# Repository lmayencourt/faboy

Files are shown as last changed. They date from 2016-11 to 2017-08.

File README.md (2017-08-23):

# faboy
arduboy clone for the fablab of Sion (CH)

## faboyBLE (V2)
The new version of the faboy is based on a nrf52822 module, an ARM cortex M0+ based processor with Bluetooth Smart. This will allow the possibility to change game wia BLE or UART and to have multiplayer games.  
### status
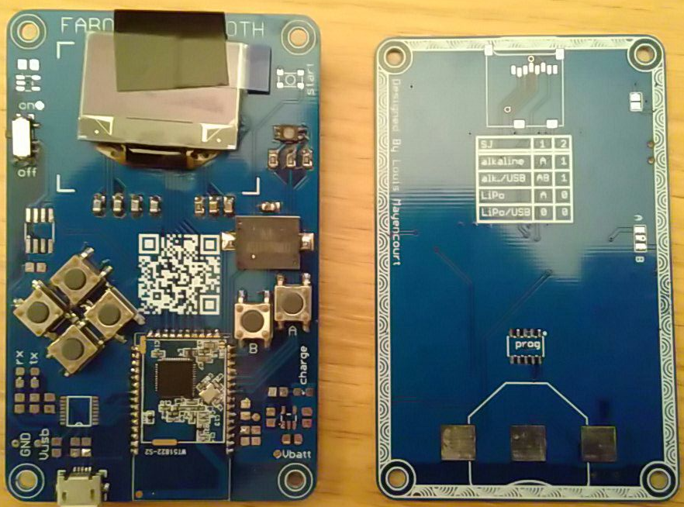
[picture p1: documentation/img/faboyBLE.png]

* PCB designed, ordered and mounted

### issues 
* cannot programm the nrf module...

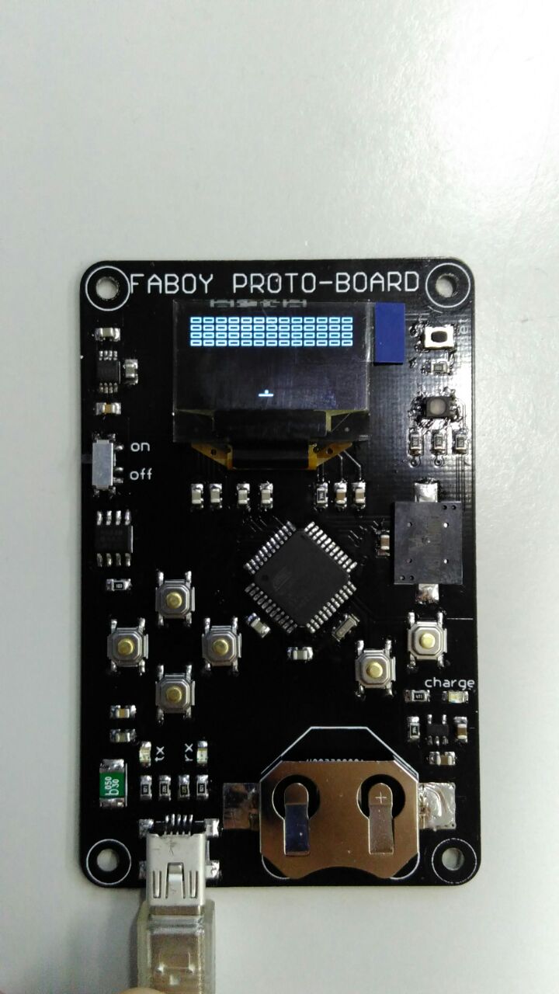
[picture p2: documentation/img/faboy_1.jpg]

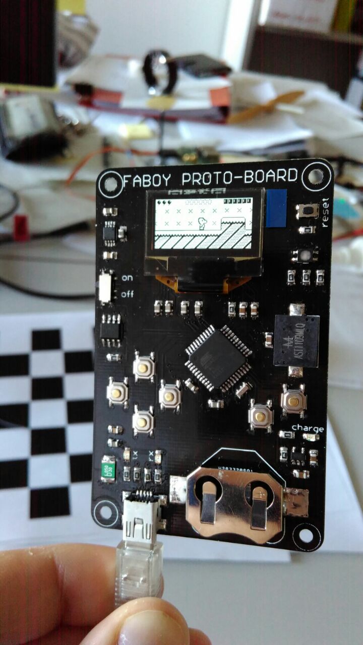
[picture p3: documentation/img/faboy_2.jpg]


## idea for v2 
  * NRF24l for a wireless communication
  * capacitive button
  * coin-cell battery / thin film battery 
  * different switch pattern
  * ARM processor 
  * solar cell
  * PCB usb connector 
  * battery monitoring with ADC

## issues 
  * bad usb connector (mini b instead of micro b !)
  * difficult to find a gnd test pad on the top 
  * battery operation crash after a small moment

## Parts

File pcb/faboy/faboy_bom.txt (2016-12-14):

Partlist exported from /home/louis/eagle/faboy/pcb/faboy/faboy.sch at 01.12.16 16:03

Part Value                           Device                          Package                       Description                                                                             PROD_ID    VALUE
BAT1                                 BATTERY20SMD                    BATTCON_20MM                  Battery Holders                                                                                         
C1   1uF                             C-EUC0805K                      C0805K                        CAPACITOR, European symbol                                                                              
C2   1uF                             C-EUC0805K                      C0805K                        CAPACITOR, European symbol                                                                              
C3   4.7uF / 10v                     C-EUC0805K                      C0805K                        CAPACITOR, European symbol                                                                              
C4   2.2uF                           C-EUC0805K                      C0805K                        CAPACITOR, European symbol                                                                              
C5   1uF                             C-EUC0805K                      C0805K                        CAPACITOR, European symbol                                                                              
C6   1uF                             C-EUC0805K                      C0805K                        CAPACITOR, European symbol                                                                              
C7   1uF                             C-EUC0805K                      C0805K                        CAPACITOR, European symbol                                                                              
C8   1uF                             C-EUC0805K                      C0805K                        CAPACITOR, European symbol                                                                              
C9   0.1uF                           C-EUC0805K                      C0805K                        CAPACITOR, European symbol                                                                              
C10  1uF                             C-EUC0805K                      C0805K                        CAPACITOR, European symbol                                                                              
C11  0.47uF                          C-EUC0805K                      C0805K                        CAPACITOR, European symbol                                                                              
C12  2.2uF                           C-EUC0805K                      C0805K                        CAPACITOR, European symbol                                                                              
C13  2.2uF                           C-EUC0805K                      C0805K                        CAPACITOR, European symbol                                                                              
C14  4.7uF                           C-EUC0805K                      C0805K                        CAPACITOR, European symbol                                                                              
C15  4.7uF                           C-EUC0805K                      C0805K                        CAPACITOR, European symbol                                                                              
C16  4.7uF                           C-EUC0805K                      C0805K                        CAPACITOR, European symbol                                                                              
F1   500mA                           PTCFUSE-1812                    1812                          PTC fuses, resettable thermistors                                                                       
J1   USB-MICROBREDUCED_PASTE         USB-MICROBREDUCED_PASTE         USB-B-MICRO-SMD_V03_RED_PASTE RED_PASTE version has 70% paste area under D+ D- USBID pins for applications            CONN-11752      
J2                                   M06SMD-FEMALE-V2                1X06-SMD-FEMALE-V2            Header 6                                                                                CONN-09668      
LED1                                 LEDSML0805                      SML0805                       LED                                                                                                     
LED2                                 LEDSML0805                      SML0805                       LED                                                                                                     
LED3                                 LEDSML0805                      SML0805                       LED                                                                                                     
R1   390k                            R-EU_R0805                      R0805                         RESISTOR, European symbol                                                                               
R2   10k                             R-EU_R0805                      R0805                         RESISTOR, European symbol                                                                               
R3   22                              R-EU_R0805                      R0805                         RESISTOR, European symbol                                                                               
R4   22                              R-EU_R0805                      R0805                         RESISTOR, European symbol                                                                               
R5   820                             R-EU_R0805                      R0805                         RESISTOR, European symbol                                                                               
R6   820                             R-EU_R0805                      R0805                         RESISTOR, European symbol                                                                               
R7   390k                            R-EU_R0805                      R0805                         RESISTOR, European symbol                                                                               
R8   470                             R-EU_R0805                      R0805                         RESISTOR, European symbol                                                                               
R9   820                             R-EU_R0805                      R0805                         RESISTOR, European symbol                                                                               
R10  820                             R-EU_R0805                      R0805                         RESISTOR, European symbol                                                                               
R11  820                             R-EU_R0805                      R0805                         RESISTOR, European symbol                                                                               
R12  10k                             R-EU_R0805                      R0805                         RESISTOR, European symbol                                                                               
S1   SWITCH-MOMENTARY-2SMD-REDUNDANT SWITCH-MOMENTARY-2SMD-REDUNDANT TACTILE-SWITCH-SMD            Various NO switches- pushbuttons, reed, etc                                             SWCH-08247      
S2   SWITCH-MOMENTARY-2SMD-REDUNDANT SWITCH-MOMENTARY-2SMD-REDUNDANT TACTILE-SWITCH-SMD            Various NO switches- pushbuttons, reed, etc                                             SWCH-08247      
S3   SWITCH-MOMENTARY-2SMD-REDUNDANT SWITCH-MOMENTARY-2SMD-REDUNDANT TACTILE-SWITCH-SMD            Various NO switches- pushbuttons, reed, etc                                             SWCH-08247      
S4   SWITCH-MOMENTARY-2SMD-REDUNDANT SWITCH-MOMENTARY-2SMD-REDUNDANT TACTILE-SWITCH-SMD            Various NO switches- pushbuttons, reed, etc                                             SWCH-08247      
S5                                   SWITCH-SPDT-SMD-A               SWITCH-SPST-SMD-A             SPDT Switch                                                                             SWCH-10651      
S6   SWITCH-MOMENTARY-2SMD-REDUNDANT SWITCH-MOMENTARY-2SMD-REDUNDANT TACTILE-SWITCH-SMD            Various NO switches- pushbuttons, reed, etc                                             SWCH-08247      
S7   SWITCH-MOMENTARY-2SMD-REDUNDANT SWITCH-MOMENTARY-2SMD-REDUNDANT TACTILE-SWITCH-SMD            Various NO switches- pushbuttons, reed, etc                                             SWCH-08247      
S8   SWITCH-MOMENTARY-2SMD-3         SWITCH-MOMENTARY-2SMD-3         TACTILE_SWITCH_SMD-3          Various NO switches- pushbuttons, reed, etc                                                             
SG1  BUZZERSMD3                      BUZZERSMD3                      BUZZER-CMT1102                Buzzer 12mm                                                                                             
SJ1  direct power                    SJ                              SJ                            SMD solder JUMPER                                                                                       
SJ3  direct path                     SJ2W                            SJ_2                          SMD solder JUMPER                                                                                       
U$1  UG-2864HSWEG01                  UG-2864HSWEG01                  1X30-0.7MM                    UG-2864HSWEG01 OLED display                                                                             
U$2  ATMEGA32U4-AU                   ATMEGA32U4-AU                   TQFP44                        http://www.ladyada.net/library/eagle                                                                    
U$7  LED-RGB-P-LCC-4                 LED-RGB-P-LCC-4                 P-LCC-4-3                                                                                                                             
U$8  SI4833BDY                       SI4833BDY                       SO08                                                                                                                                  
U1   MAX1595UMAX                     MAX1595UMAX                     UMAX8                         max1595 buck/boost dcdc 3.3v output                                                                     
U2   MCP73831                        MCP73831                        SOT23-5                       Miniature single cell, fully integrated Li-Ion, Li-polymer charge management controller IC-09995        
Y1   16MHZ                           RESONATOR16MHZ                  RESONATOR-SMD                 Resonator                                                                               XTAL-08900 16MHZ

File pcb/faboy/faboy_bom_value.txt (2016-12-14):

Partlist exported from /home/louis/eagle/faboy/pcb/faboy/faboy.sch at 01.12.16 16:02

Qty Value                           Device                          Package                       Parts                       Description                                                                             PROD_ID    VALUE
1                                   BATTERY20SMD                    BATTCON_20MM                  BAT1                        Battery Holders                                                                                         
3                                   LEDSML0805                      SML0805                       LED1, LED2, LED3            LED                                                                                                     
1                                   M06SMD-FEMALE-V2                1X06-SMD-FEMALE-V2            J2                          Header 6                                                                                CONN-09668      
1                                   SWITCH-SPDT-SMD-A               SWITCH-SPST-SMD-A             S5                          SPDT Switch                                                                             SWCH-10651      
1   0.1uF                           C-EUC0805K                      C0805K                        C9                          CAPACITOR, European symbol                                                                              
1   0.47uF                          C-EUC0805K                      C0805K                        C11                         CAPACITOR, European symbol                                                                              
2   10k                             R-EU_R0805                      R0805                         R2, R12                     RESISTOR, European symbol                                                                               
1   16MHZ                           RESONATOR16MHZ                  RESONATOR-SMD                 Y1                          Resonator                                                                               XTAL-08900 16MHZ
7   1uF                             C-EUC0805K                      C0805K                        C1, C2, C5, C6, C7, C8, C10 CAPACITOR, European symbol                                                                              
3   2.2uF                           C-EUC0805K                      C0805K                        C4, C12, C13                CAPACITOR, European symbol                                                                              
2   22                              R-EU_R0805                      R0805                         R3, R4                      RESISTOR, European symbol                                                                               
2   390k                            R-EU_R0805                      R0805                         R1, R7                      RESISTOR, European symbol                                                                               
3   4.7uF                           C-EUC0805K                      C0805K                        C14, C15, C16               CAPACITOR, European symbol                                                                              
1   4.7uF / 10v                     C-EUC0805K                      C0805K                        C3                          CAPACITOR, European symbol                                                                              
1   470                             R-EU_R0805                      R0805                         R8                          RESISTOR, European symbol                                                                               
1   500mA                           PTCFUSE-1812                    1812                          F1                          PTC fuses, resettable thermistors                                                                       
5   820                             R-EU_R0805                      R0805                         R5, R6, R9, R10, R11        RESISTOR, European symbol                                                                               
1   ATMEGA32U4-AU                   ATMEGA32U4-AU                   TQFP44                        U$2                         http://www.ladyada.net/library/eagle                                                                    
1   BUZZERSMD3                      BUZZERSMD3                      BUZZER-CMT1102                SG1                         Buzzer 12mm                                                                                             
1   LED-RGB-P-LCC-4                 LED-RGB-P-LCC-4                 P-LCC-4-3                     U$7                                                                                                                                 
1   MAX1595UMAX                     MAX1595UMAX                     UMAX8                         U1                          max1595 buck/boost dcdc 3.3v output                                                                     
1   MCP73831                        MCP73831                        SOT23-5                       U2                          Miniature single cell, fully integrated Li-Ion, Li-polymer charge management controller IC-09995        
1   SI4833BDY                       SI4833BDY                       SO08                          U$8                                                                                                                                 
1   SWITCH-MOMENTARY-2SMD-3         SWITCH-MOMENTARY-2SMD-3         TACTILE_SWITCH_SMD-3          S8                          Various NO switches- pushbuttons, reed, etc                                                             
6   SWITCH-MOMENTARY-2SMD-REDUNDANT SWITCH-MOMENTARY-2SMD-REDUNDANT TACTILE-SWITCH-SMD            S1, S2, S3, S4, S6, S7      Various NO switches- pushbuttons, reed, etc                                             SWCH-08247      
1   UG-2864HSWEG01                  UG-2864HSWEG01                  1X30-0.7MM                    U$1                         UG-2864HSWEG01 OLED display                                                                             
1   USB-MICROBREDUCED_PASTE         USB-MICROBREDUCED_PASTE         USB-B-MICRO-SMD_V03_RED_PASTE J1                          RED_PASTE version has 70% paste area under D+ D- USBID pins for applications            CONN-11752      
1   direct path                     SJ2W                            SJ_2                          SJ3                         SMD solder JUMPER                                                                                       
1   direct power                    SJ                              SJ                            SJ1                         SMD solder JUMPER

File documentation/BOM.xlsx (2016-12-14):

 | link | reference | description | price | nbr | total
mouser | http://www.mouser.ch/ProductDetail/Atmel/ATMEGA32U4-AU/?qs=sGAEpiMZZMvAvBNgSS9Lqh1wBIpnYT9c | ATMEGA32u4-AU | 8bits 32k cpu | 6.33 | 1 | 6.33
mouser | http://www.mouser.ch/Search/ProductDetail.aspx?qs=8%2f1pEl6ptNseo9Gxrhu%2fPA%3d%3d | CSTCE16M0V53ZW-R0 | resonator 16Mhz | 0.5 | 1 | 0.5
mouser | http://www.mouser.ch/ProductDetail/Microchip-Technology/MCP73831T-2ACI-OT/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 | MCP73831 | MCP73831 LiPo charger | 0.6 | 1 | 0.6
mouser | http://www.mouser.ch/ProductDetail/Maxim-Integrated/MAX1595EUA33+/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 | MAX1595EUA33 | buck/boost 3.3v dcdc | 3.88 | 1 | 3.88
mouser | http://www.mouser.ch/ProductDetail/Vishay/SI4833BDY-T1-GE3/ | SI4833BDY | P-mosfet with schottky | 0.66 | 1 | 0.66
mouser |  | UJ2-MBH-1-SMT | conn USB mini B femal | 0.78 | 1 | 0.78
mouser |  |  | conn USB Micro B femal | 0.7 | 1 | 0.7
mouser |  | AP2012SRCPRV | led red | 0.14 |  | 0
mouser |  | LTST-C170TBKT | led blue | 0.4 |  | 0
mouser |  | APT2012SGC | led green | 0.14 |  | 0
mouser | http://www.mouser.ch/ProductDetail/Mallory-Sonalert/AST1109MLTRQ/ | AST1109MLTRQ | piezzo | 3.2 | 1 | 3.2
mouser | http://www.mouser.ch/ProductDetail/ALPS/SKQGAKE010/?qs=sGAEpiMZZMtFyPk3yBMYYCtu4vPfeeUaHHDNk5wDwBc%3d | SKQGAKE010 | push button | 0.16 | 6 | 0.96
mouser | http://www.mouser.ch/ProductDetail/CK-Components/SK-12C0405-SG-15-RT/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 | SK-12C0405-SG 1.5 RT | switch on-off | 0.97 | 1 | 0.97
mouser | http://www.mouser.ch/ProductDetail/CK-Components/KMR631NG-ULC-LFS/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 | KMR631NG ULC LFS | reset push buton | 0.27 | 1 | 0.27
mouser | http://www.mouser.ch/ProductDetail/Cree-Inc/CLVBA-FKA-CAEDH8BBB7A363/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 | CLVBA-FKA-CAEDH8BBB7A363 | led RGB | 0.48 | 1 | 0.48
mouser | http://www.mouser.ch/ProductDetail/Linx-Technologies/BAT-HLD-002-SMT/ | BAT-HLD-002-SMT | support CR2016 | 0.28 | 1 | 0.28
alibaba | https://www.alibaba.com/product-detail/2016-hot-sale-lithium-polymer-battery_60437032979.html | GEB014461 | LiPo 3.6V 180 mAh | 5 | 0 | 0
buydisplay | http://www.buydisplay.com/default/datasheet-128x64-oled-module-spi-0-96-inch-graphic-displays-white-on-black | ER-OLED0.96-1 | oled white on black 128x64 0.96'' | 3.61 | 0 | 0
buydisplay | http://www.buydisplay.com/default/serial-spi-1-3-inch-128x64-oled-display-module-ssd1306-white-on-black | ER-OLED013-1W | oled white on black 128x64 1.3'' | 6.17 | 1 | 6.17
seeed |  | PCB | pcb 85.6x53.98 x 0.6mm 2 layers black | 3 | 1 | 3
 |  |  |  |  |  | 28.78

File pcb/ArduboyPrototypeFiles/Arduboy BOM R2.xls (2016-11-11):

Arduboy Bill of Materials |  | 2014-03-16
kevin@bateske.com |  | Confidential
Name | Part Number | Link | Qty
OLED DISPLAY | White 0.96 inch 128x64 OLED |  | 1
ATMEGA328P | ATMEGA328P-AU TQFP32 | http://www.mouser.com/ProductDetail/Atmel/ATMEGA328P-AU/ | 1
Resistor 10K Ohm | 0805 10K Ohm Resistor | any 5% is fine | 1
Capacitor 1uF | 0805 1uF Capacitor | any 5% is fine | 2
Rechargable Battery | LIR-2016 | ??? | 1
Speaker | SMT-1141 | http://www.mouser.com/ProductDetail/PUI-Audio/SMT-1141-T-3-R/ | 1
Capacitor .1uF | 0805 .1uF Capacitor | any 5% is fine | 2
Capacitor 10uF | 0805 10uF Capacitor | any 5% is fine | 2
LiPo-Charger | MCP73831 | http://www.mouser.com/ProductDetail/Microchip-Technology/MCP73831T-2ACI-OT/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 | 1
2.2uf
4.7uf
2k
Board Dimensions:
Height: | 85.6mm
Width: | 53.98mm
Thickness: | 1.6mm
Cutouts (Routing) | Qty(5)
Drills: | Qty(8)
Plated Vias | Qty(29)

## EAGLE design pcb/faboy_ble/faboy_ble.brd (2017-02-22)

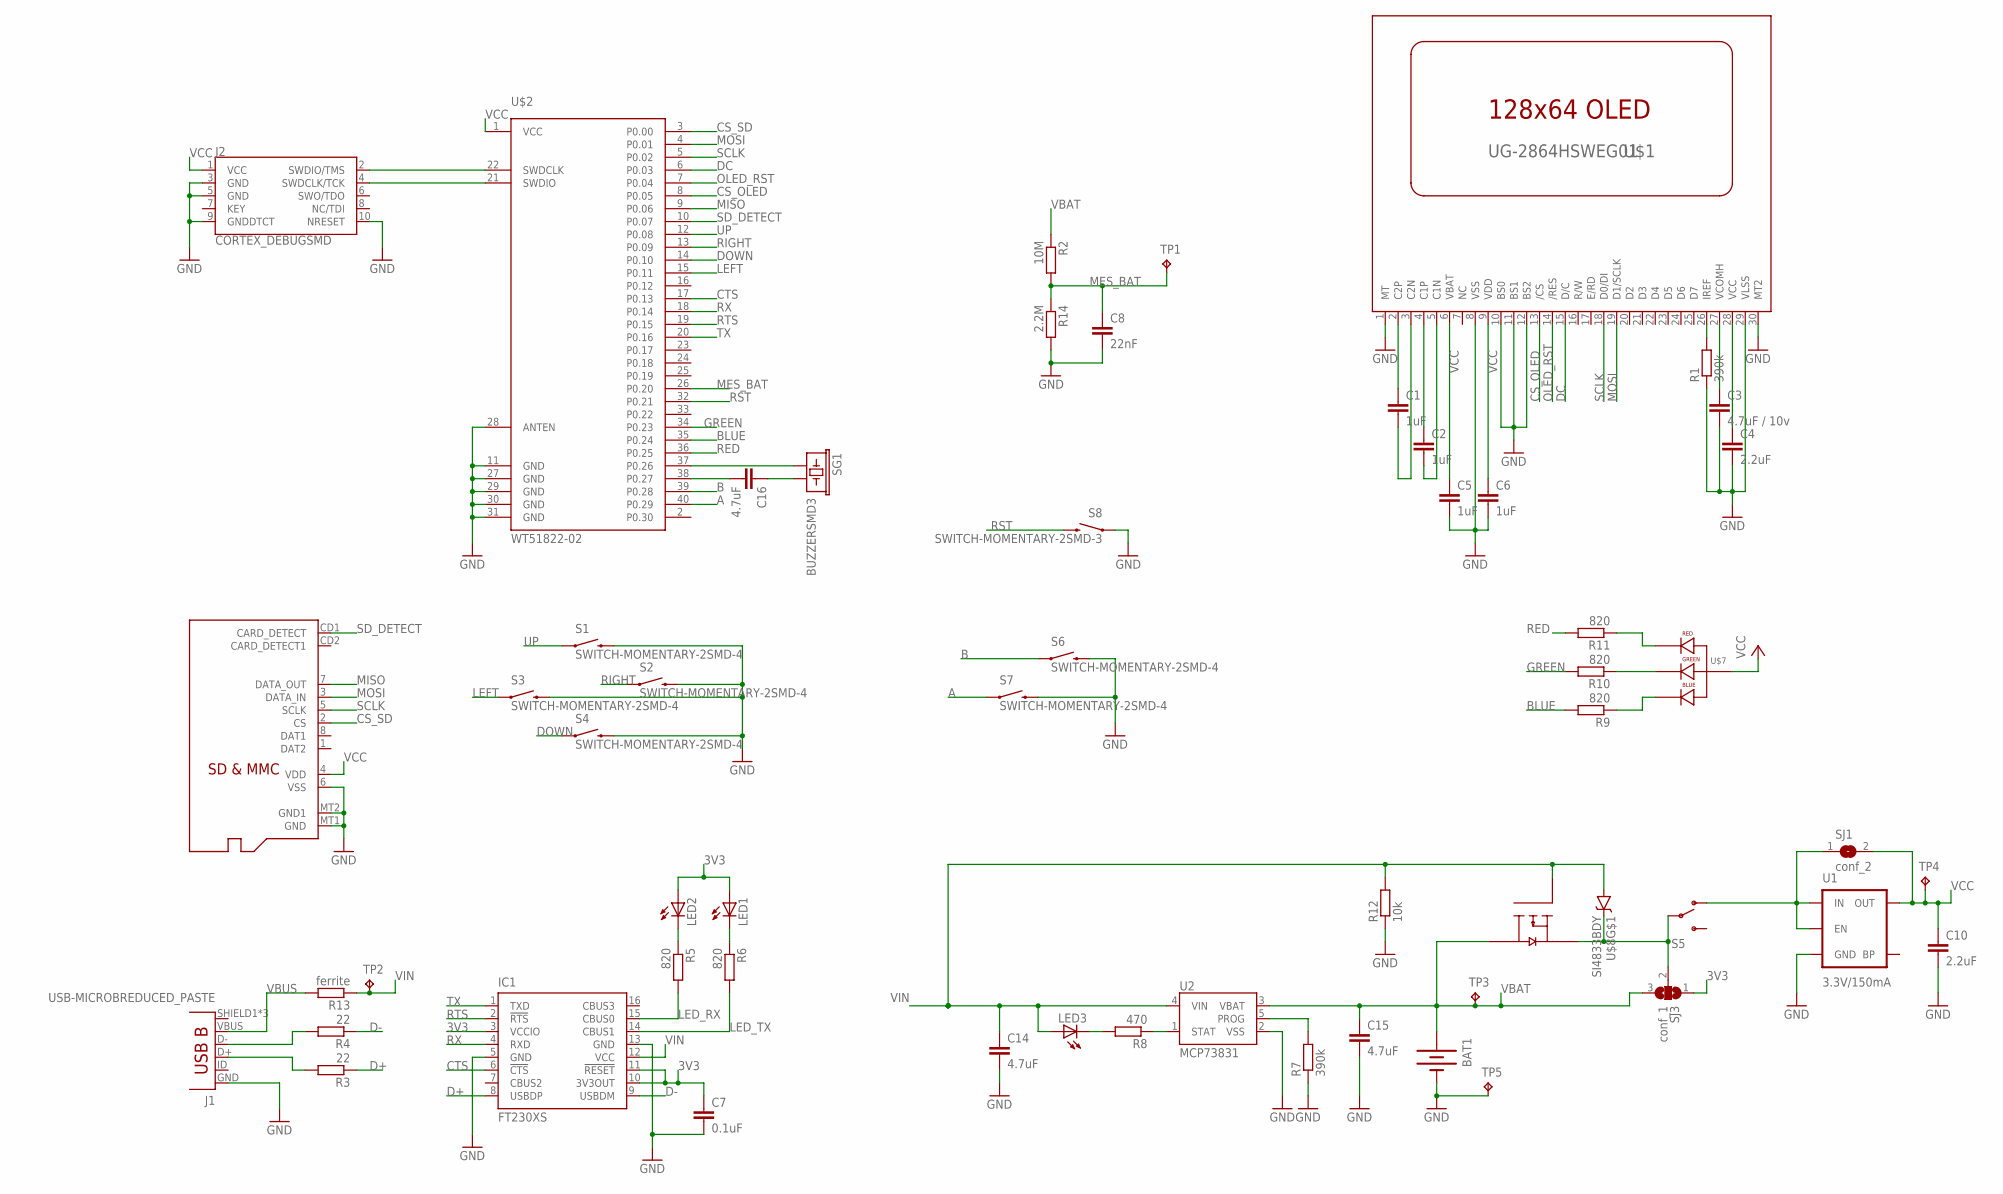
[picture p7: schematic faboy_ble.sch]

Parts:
BAT1: BATTERY20SMD; BATTCON_20MM
C1, C2, C5, C6: 1uF; C0805K
C3: 4.7uF / 10v; C0805K
C4, C10: 2.2uF; C0805K
C7: 0.1uF; C0805K
C8: 22nF; C0805K
C14, C15, C16: 4.7uF; C0805K
IC1: FT230XS; SSOP16
J1: USB-MICROBREDUCED_PASTE; USB-B-MICRO-SMD_V03_RED_PASTE
J2: CORTEX_DEBUGSMD; SAMTECH_FTSH-105-01
LED1, LED2, LED3: LEDSML0805; SML0805
R1, R7: 390k; R0805
R2: 10M; R0805
R3, R4: 22; R0805
R5, R6, R9, R10, R11: 820; R0805
R8: 470; R0805
R12: 10k; R0805
R13: ferrite; R0805
R14: 2.2M; R0805
S1, S2, S3, S4, S6, S7: SWITCH-MOMENTARY-2SMD-4; TACTILE_SWITCH_TALL
S5: SWITCH-SPDT-SMD-A; SWITCH-SPST-SMD-A
S8: SWITCH-MOMENTARY-2SMD-3; TACTILE_SWITCH_SMD-3
SG1: BUZZERSMD3; BUZZER-CMT1102
SJ1: conf_2; SJ
SJ3: conf_1; SJ_2
TP1, TP2, TP3, TP4, TP5: TPB1,27; B1,27
U1: 3.3V/150mA; SOT23-5
U2: MCP73831; SOT23-5
U$1: UG-2864HSWEG01; 1X30-0.7MM
U$2: WT51822-02; WT51822
U$7: LED-RGB-P-LCC-4; P-LCC-4-3
U$8: SI4833BDY; SO08
U$9: MICROSD

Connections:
3V3: C7.1, IC1.3 (VCCIO), IC1.10 (3V3OUT), IC1.11 (!RESET), LED1.A, LED2.A, SJ3.1
A: S7.A2 (1), U$2.40 (P0.29)
B: S6.A2 (1), U$2.39 (P0.28)
BLUE: R9.2, U$2.35 (P0.24)
CS_OLED: U$1.13 (/CS), U$2.8 (P0.05)
CS_SD: U$2.3 (P0.00), U$9.2 (CS)
CTS: IC1.6 (!CTS), U$2.17 (P0.13)
D+: IC1.8 (USBDP), R3.1
D-: IC1.9 (USBDM), R4.1
DC: U$1.15 (D/C), U$2.6 (P0.03)
DOWN: S4.A2 (1), U$2.14 (P0.10)
GND: BAT1.2 (-), C3.2, C4.2, C5.2, C6.2, C7.2, C8.2, C10.2, C14.2, C15.2, IC1.5 (GND), IC1.13 (GND), J1.GND, J2.3 (GND), J2.5 (GND), J2.9 (GNDDTCT), J2.10 (NRESET), R1.1, R7.1, R12.1, R14.2, S1.B2 (2), S2.B2 (2), S3.B2 (2), S4.B2 (2), S6.B2 (2), S7.B2 (2), S8.1, TP5.TP, U1.2 (GND), U2.2 (VSS), U$1.1 (MT), U$1.8 (VSS), U$1.10 (BS0), U$1.11 (BS1), U$1.12 (BS2), U$1.29 (VLSS), U$1.30 (MT2), U$2.11 (GND), U$2.27 (GND), U$2.28 (ANTEN), U$2.29 (GND), U$2.30 (GND), U$2.31 (GND)
GREEN: R10.2, U$2.34 (P0.23)
LED_RX: IC1.15 (CBUS0), R5.2
LED_TX: IC1.14 (CBUS1), R6.2
LEFT: S3.A2 (1), U$2.15 (P0.11)
MES_BAT: C8.1, R2.2, R14.1, TP1.TP, U$2.26 (P0.20)
MISO: U$2.9 (P0.06), U$9.7 (DATA_OUT)
MOSI: U$1.19 (D1/SCLK), U$2.4 (P0.01), U$9.3 (DATA_IN)
unnamed: C1.1, U$1.2 (C2P)
unnamed: C1.2, U$1.3 (C2N)
unnamed: C2.1, U$1.4 (C1P)
unnamed: C2.2, U$1.5 (C1N)
unnamed: R1.2, U$1.26 (IREF)
unnamed: R11.1, U$7.1 (RED_CATHODE)
unnamed: C3.1, U$1.27 (VCOMH)
unnamed: C4.1, U$1.28 (VCC)
unnamed: S5.1 (O), SJ1.1, U1.1 (IN), U1.3 (EN)
unnamed: C16.2, U$2.38 (P0.27)
unnamed: C16.1, SG1.2
unnamed: J1.D+, R3.2
unnamed: J1.D-, R4.2
unnamed: R8.1, U2.1 (STAT)
unnamed: LED3.C, R8.2
unnamed: R7.2, U2.5 (PROG)
unnamed: SG1.1, U$2.37 (P0.26)
unnamed: R10.1, U$7.4 (GREEN_CATHODE)
unnamed: LED2.C, R5.1
unnamed: R9.1, U$7.3 (BLUE_CATHODE)
unnamed: LED1.C, R6.1
unnamed: S5.2, SJ3.2, U$8.3 (S2), U$8.7 (C), U$8.8 (C)
OLED_RST: U$1.14 (/RES), U$2.7 (P0.04)
RED: R11.2, U$2.36 (P0.25)
RIGHT: S2.A2 (1), U$2.13 (P0.09)
RST: S8.4 (2), U$2.32 (P0.21)
RTS: IC1.2 (!RTS), U$2.19 (P0.15)
RX: IC1.4 (RXD), U$2.18 (P0.14)
SCLK: U$1.18 (D0/DI), U$2.5 (P0.02), U$9.5 (SCLK)
SD_DETECT: U$2.10 (P0.07), U$9.CD1 (CARD_DETECT)
SWDCLK: J2.4 (SWDCLK/TCK), U$2.21 (SWDIO)
SWDIO: J2.2 (SWDIO/TMS), U$2.22 (SWDCLK)
TX: IC1.1 (TXD), U$2.20 (P0.16)
UP: S1.A2 (1), U$2.12 (P0.08)
VBAT: BAT1.3 (+), C15.1, R2.1, SJ3.3, TP3.TP, U2.3 (VBAT), U$8.5 (D2), U$8.6 (D2)
VBUS: J1.VBUS, R13.2
VCC: C5.1, C6.1, C10.1, J2.1 (VCC), SJ1.2, TP4.TP, U1.5 (OUT), U$1.6 (VBAT), U$1.9 (VDD), U$2.1 (VCC), U$7.2 (ANODE), U$9.4 (VDD)
VIN: C14.1, IC1.12 (VCC), LED3.A, R12.2, R13.1, TP2.TP, U2.4 (VIN), U$8.1 (A), U$8.2 (A), U$8.4 (G2)
VSS: U$9.6 (VSS), U$9.MT1 (GND), U$9.MT2 (GND1)

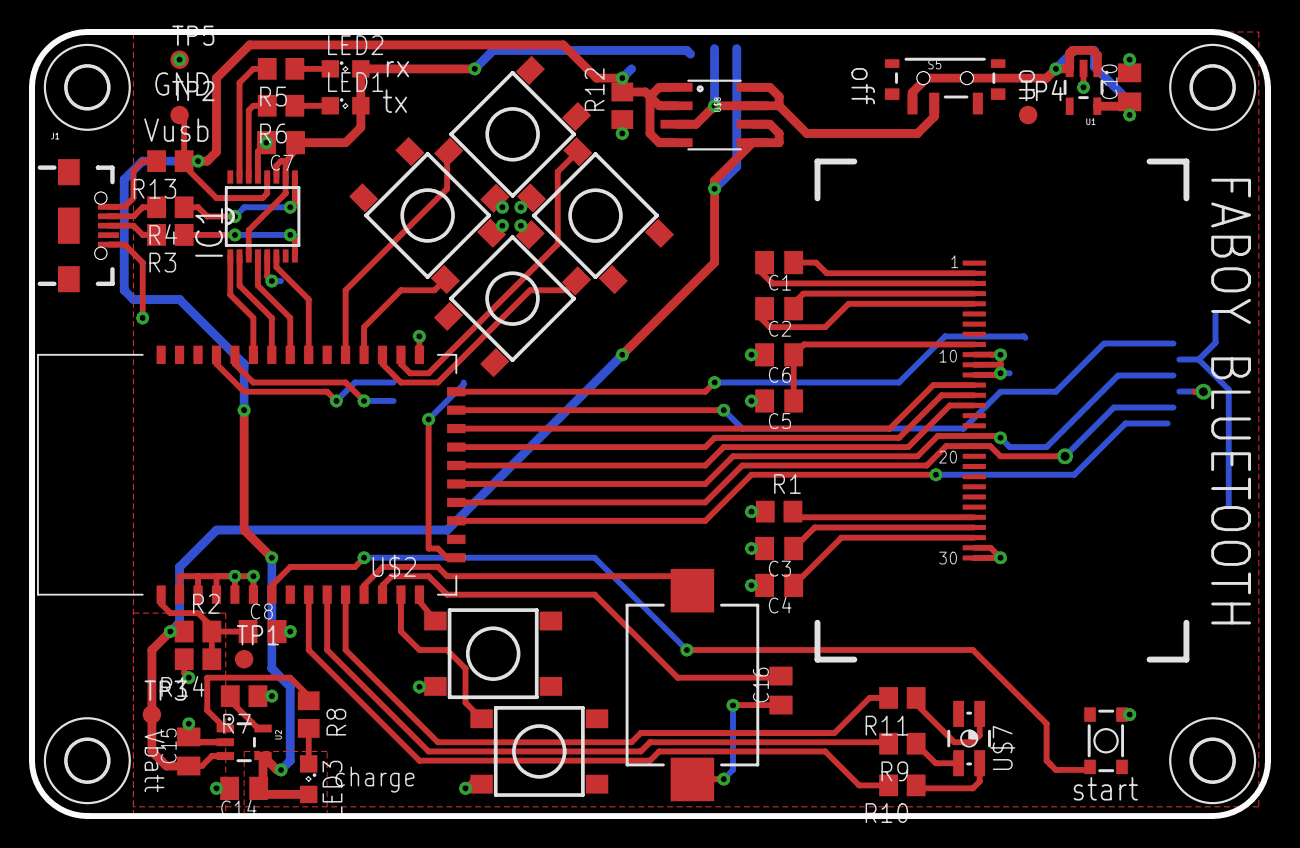
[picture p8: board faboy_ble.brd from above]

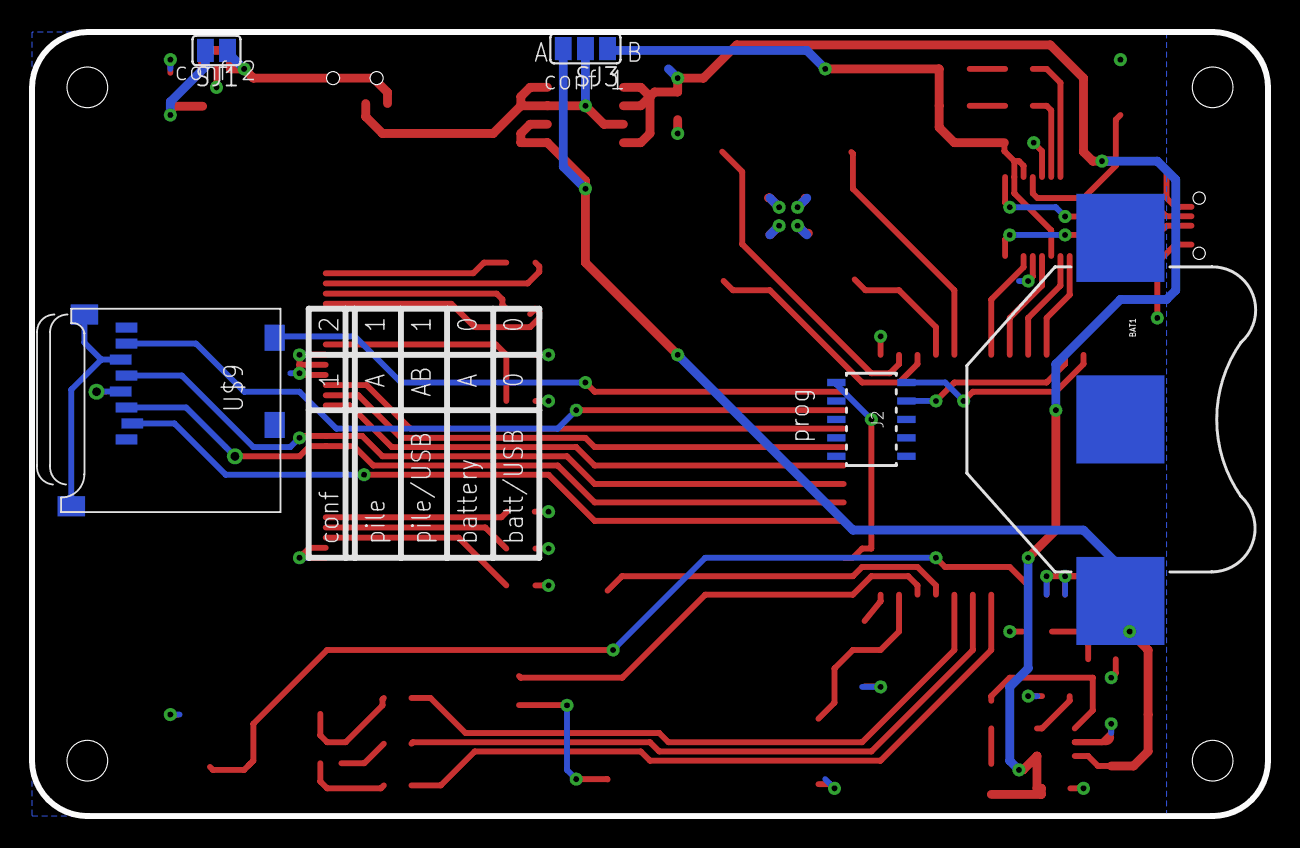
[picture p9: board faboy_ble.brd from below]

Board: 2 copper layers, 85.1 x 54.0 mm, 60 parts (5 on the bottom side), 58 nets.

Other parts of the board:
U$3, U$4, U$6: 2,8
U$5: gnd; 2,8

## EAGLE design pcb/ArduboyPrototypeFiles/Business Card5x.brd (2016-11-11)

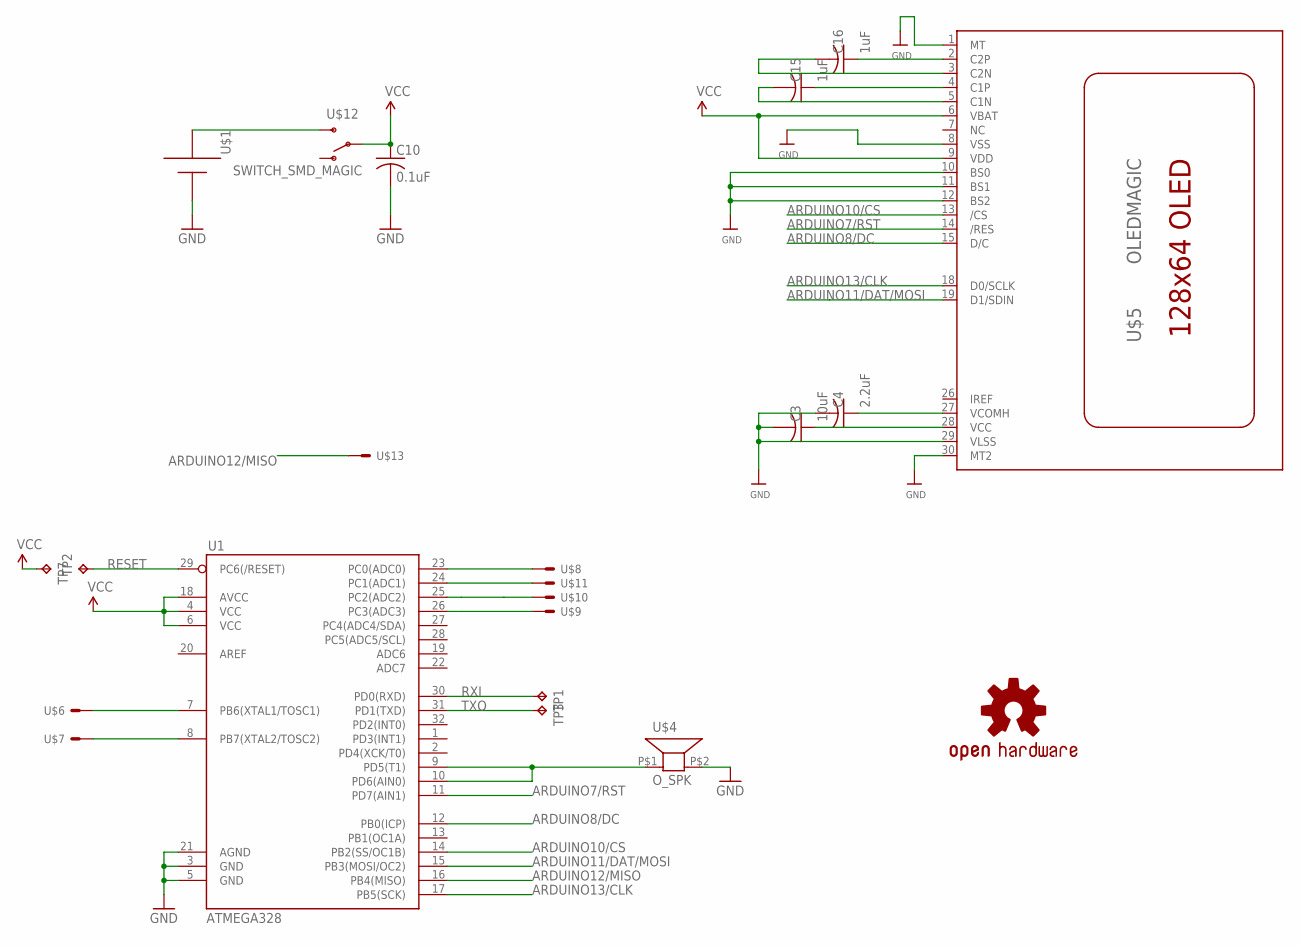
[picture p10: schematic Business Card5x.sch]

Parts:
C3: 10uF; 1MILCIR
C4: 2.2uF; 1MILCIR
C10: 0.1uF; 1MILCIR
C15, C16: 1uF; 1MILCIR
TP1, TP2, TP3: TPTP14R; TP14R
TP7: TPTP08SQ; TP08SQ
U1: ATMEGA328; TQFP32
U$1: 2016BAT; CR2016
U$3: OSHW-LOGOS; OSHW-LOGO-S
U$4: O_SPK
U$5: OLEDMAGIC; 1X30OLED
U$6, U$7: CAP_BUTTON; CAPBUTTON
U$8, U$9, U$10, U$11: CAP_DPAD; DPAD
U$12: SWITCH_SMD_MAGIC; SWITCH_SMD_SUNKEN
U$13: VERT_TEST

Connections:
3.3V: C10.P$1 (1), TP7.TP, U1.4 (VCC), U1.6 (VCC), U1.18 (AVCC), U$5.6 (VBAT), U$5.9 (VDD), U$12.2
ARDUINO7/RST: U1.11 (PD7(AIN1)), U$5.14 (/RES)
ARDUINO8/DC: U1.12 (PB0(ICP)), U$5.15 (D/C)
ARDUINO10/CS: U1.14 (PB2(SS/OC1B)), U$5.13 (/CS)
ARDUINO11/DAT/MOSI: U1.15 (PB3(MOSI/OC2)), U$5.19 (D1/SDIN)
ARDUINO12/MISO: U1.16 (PB4(MISO)), U$13.P$1
ARDUINO13/CLK: U1.17 (PB5(SCK)), U$5.18 (D0/SCLK)
GND: C3.P$2 (2), C4.P$2 (2), C10.P$2 (2), U1.3 (GND), U1.5 (GND), U1.21 (AGND), U$1.P$1 (+), U$4.P$2 (2), U$5.1 (MT), U$5.8 (VSS), U$5.10 (BS0), U$5.11 (BS1), U$5.12 (BS2), U$5.29 (VLSS), U$5.30 (MT2)
unnamed: U1.23 (PC0(ADC0)), U$8.P$1
unnamed: U1.24 (PC1(ADC1)), U$11.P$1
unnamed: U1.25 (PC2(ADC2)), U$10.P$1
unnamed: U1.26 (PC3(ADC3)), U$9.P$1
unnamed: C16.P$1 (1), U$5.2 (C2P)
unnamed: C16.P$2 (2), U$5.3 (C2N)
unnamed: U1.9 (PD5(T1)), U1.10 (PD6(AIN0)), U$4.P$1 (1)
unnamed: C15.P$1 (1), U$5.4 (C1P)
unnamed: C15.P$2 (2), U$5.5 (C1N)
unnamed: U1.7 (PB6(XTAL1/TOSC1)), U$6.P$1, U$6.P$2
unnamed: C3.P$1 (1), U$5.28 (VCC)
unnamed: C4.P$1 (1), U$5.27 (VCOMH)
unnamed: U1.8 (PB7(XTAL2/TOSC2)), U$7.P$1, U$7.P$2
unnamed: U$1.P$2 (-), U$12.3 (S)
RESET: TP2.TP, U1.29 (PC6(/RESET))
RXI: TP1.TP, U1.30 (PD0(RXD))
TXO: TP3.TP, U1.31 (PD1(TXD))

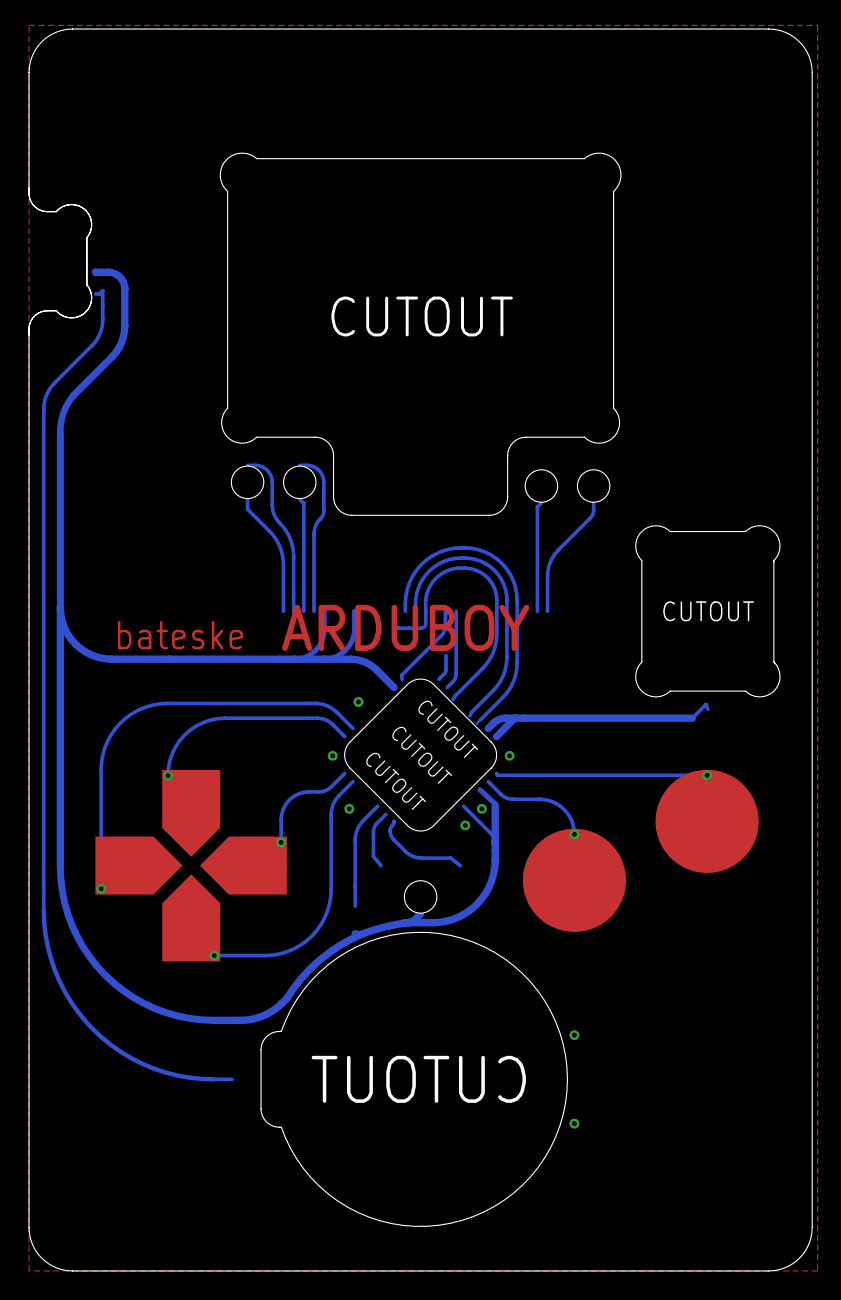
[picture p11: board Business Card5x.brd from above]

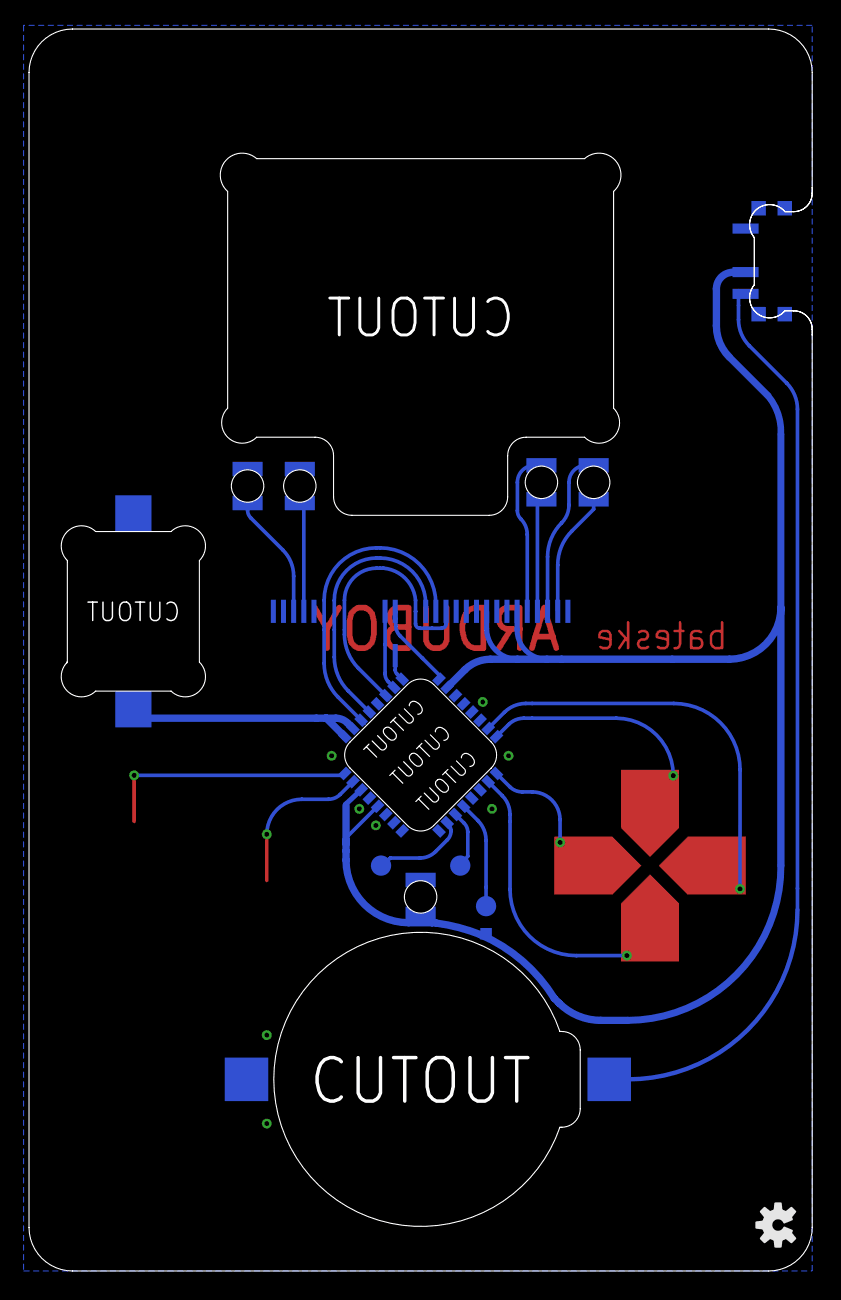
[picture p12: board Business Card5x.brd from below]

Board: 2 copper layers, 54.0 x 85.6 mm, 22 parts (13 on the bottom side), 25 nets.

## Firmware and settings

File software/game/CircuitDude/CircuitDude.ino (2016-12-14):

//Circuit Dude
//	Version 1.0, November 17, 2016
//	By Jonathan Holmes (crait)
//
//	Website: http://www.crait.net/
//	Twitter: @crait
//	Make your own levels: http://www.crait.net/circuitdude/
//
//Help Circuit Dude build an awesome invention by leading him
//through 50 unique levels, completing circuits and plugging
//in microchips. After all chips are inserted into their sockets,
//the exit will activate and you can advance to the next puzzle!
//What kind of secret invention is Circuit Dude building?
//Complete all 50 levels to find out!
//
//
//1.0 - November 17, 2016
//	Initial release



//	Align and clean up menu text
//	

#include <Arduboy.h>
#include <EEPROM.h>

Arduboy arduboy;
#define OFF HIGH
#define ON LOW
#define SAVELOCATION (EEPROM_STORAGE_SPACE_START + 410)

boolean menubuttonfree = true;
char menubuttoncounter = 0;
boolean gamebuttonfree = true;
int frame = 0;
char animation = 0;
char transitionanimation = 0;
char deathcounter = 0;
char gamestate = 0;
char level = 0;
boolean levelcomplete = false;
char levelcompletecounter = 0;
char playerx = 0;
char playery = 0;
char playertox = 0;
char playertoy = 0;
boolean canswitch = true;
char temperature = 0;
char maxlevel = 0;
char levelchecker = 0;
boolean soundon = true;

const unsigned char lock[] PROGMEM = {
  0x7e, 0x79, 0x59, 0x79, 0x7e
};

const unsigned char me[] PROGMEM = {
	0x45, 0x8a, 0x15, 0xaa, 0x15, 0xaa, 0xd5, 0x6a,
	0x34, 0x28, 0x21, 0x32, 0x1d, 0x0a, 0x0c, 0x06,
	0x03, 0x02, 0x07, 0x02, 0x23, 0x41, 0xa0, 0x41,
	0x80, 0x40, 0x81, 0x40, 0x20, 0x80, 0x40, 0x80,
	0x40, 0x20, 0x08, 0xc7, 0x7d, 0xa2, 0x55, 0xa2,
	0x51, 0xa8, 0x15, 0x88, 0x44, 0xa2, 0x51, 0xaa,
	0x54, 0xa8, 0x51, 0x82, 0x05, 0xff, 0x00, 0x00,
	0x41, 0x80, 0x80, 0x00, 0x80, 0xe0, 0xf0, 0xf0,
	0xf0, 0xf0, 0xe0, 0x60, 0x60, 0x60, 0x68, 0xed,
	0xe4, 0xe3, 0xe0, 0xe0, 0x61, 0x72, 0xe1, 0x02,
	0xe1, 0x32, 0x1a, 0xaf, 0x11, 0x88, 0x54, 0x8a,
	0x45, 0x2a, 0x05, 0x92, 0x45, 0xa2, 0x41, 0xa0,
	0x55, 0xaa, 0x55, 0xaa, 0x55, 0xbf, 0xe0, 0x00,
	0x00, 0x00, 0x00, 0x3c, 0xfe, 0xff, 0xff, 0xff,
	0x1d, 0xec, 0x36, 0x37, 0xf7, 0xf7, 0xee, 0x1f,
	0xff, 0x3f, 0xdf, 0x2e, 0x37, 0xf6, 0xee, 0x1c,
	0x03, 0x7e, 0x55, 0xca, 0xc5, 0xa2, 0x51, 0xa8,
	0x54, 0xaa, 0x55, 0x2a, 0x15, 0x8a, 0x45, 0x22,
	0x51, 0xa2, 0x54, 0xa0, 0x55, 0xfe, 0xc3, 0xbc,
	0x66, 0x40, 0x00, 0x38, 0xdf, 0x7f, 0xbf, 0xff,
	0xff, 0xfe, 0x7d, 0x7d, 0x7d, 0xfd, 0xfe, 0x3f,
	0x7f, 0xff, 0xf0, 0x6d, 0x1d, 0xbd, 0xfe, 0xff,
	0xe0, 0x83, 0x3f, 0xc0, 0x7f, 0xa2, 0x55, 0xa2,
	0x51, 0x28, 0x04, 0xa2, 0x51, 0xa8, 0x54, 0xaa,
	0x11, 0xa2, 0x15, 0xa2, 0xc5, 0x6a, 0x45, 0x63,
	0x41, 0x6b, 0x5e, 0x78, 0x71, 0xa6, 0x4b, 0x8d,
	0x97, 0x9c, 0x38, 0x31, 0x23, 0x06, 0x46, 0x4d,
	0x4d, 0x6d, 0x72, 0x7f, 0x6f, 0x1f, 0x37, 0x0f,
	0x1d, 0xcb, 0xe0, 0x7f, 0x55, 0x6a, 0x45, 0x40,
	0xc0, 0x8a, 0xc5, 0x6a, 0xb5, 0xda, 0xed, 0xca,
	0x3d, 0xce, 0xf3, 0xfd, 0xfe, 0xf8, 0x87, 0x7f,
	0xff, 0xff, 0xff, 0xff, 0xc0, 0xbf, 0xbe, 0xbd,
	0xdb, 0x57, 0xa7, 0xcf, 0xb7, 0x8b, 0xfa, 0xf6,
	0x76, 0xa6, 0xca, 0x76, 0xea, 0x9c, 0x5f, 0xdf,
	0xc0, 0xfe, 0xfe, 0xff, 0xff, 0xff, 0xff, 0x0f,
	0xb6, 0xb9, 0xfb, 0xf8, 0xf3, 0xf7, 0xff, 0xf8
};

const unsigned char title[] PROGMEM = {
	0xff, 0xff, 0xff, 0xff, 0xff, 0xff, 0xff, 0xff,
	0xff, 0xff, 0xff, 0xff, 0xff, 0xff, 0xff, 0xff,
	0xff, 0xff, 0xff, 0xff, 0xff, 0xff, 0xff, 0xff,
	0xff, 0xff, 0xff, 0xff, 0xff, 0xff, 0xff, 0xff,
	0xff, 0xff, 0xff, 0xff, 0xff, 0xff, 0xff, 0xff,
	0xff, 0xff, 0xff, 0xff, 0xff, 0xff, 0xff, 0xff,
	0xff, 0xff, 0xff, 0xff, 0x07, 0x03, 0x03, 0xf3,
	0xf3, 0xf3, 0xf3, 0xf3, 0xe7, 0xff, 0xff, 0xff,
	0xff, 0x33, 0x33, 0x33, 0xff, 0xff, 0xff, 0xff,
	0x3f, 0x3f, 0x3f, 0x7f, 0x3f, 0x3f, 0x3f, 0x3f,
	0xff, 0xff, 0xff, 0x7f, 0x3f, 0x3f, 0x3f, 0x3f,
	0x3f, 0x3f, 0xff, 0xff, 0xff, 0xff, 0xff, 0xff,
	0x3f, 0x3f, 0x3f, 0xff, 0xff, 0xff, 0x3f, 0x3f,
	0x3f, 0xff, 0xff, 0xff, 0x33, 0x33, 0x33, 0xff,
	0xff, 0xff, 0xff, 0x3f, 0x3f, 0x07, 0x07, 0x07,
	0x3f, 0x3f, 0xff, 0xff, 0xff, 0xff, 0xff, 0xff,
	0xff, 0xff, 0xff, 0xff, 0xff, 0xff, 0xff, 0xff,
	0xff, 0xff, 0xff, 0xff, 0xff, 0xff, 0xff, 0xff,
	0xff, 0xff, 0xff, 0xff, 0xff, 0xff, 0xff, 0xff,
	0xff, 0xff, 0xff, 0xff, 0xff, 0xff, 0xff, 0xff,
	0xff, 0xff, 0xff, 0xff, 0xff, 0xff, 0xff, 0xff,
	0xff, 0xff, 0xff, 0xff, 0xff, 0xff, 0xff, 0xff,
	0xff, 0xff, 0xff, 0xff, 0x00, 0x00, 0x00, 0x7f,
	0x7f, 0x7f, 0x7f, 0x7f, 0x3f, 0xff, 0xff, 0xff,
	0xff, 0x00, 0x00, 0x00, 0xff, 0xff, 0xff, 0xff,
	0x00, 0x00, 0x00, 0xfe, 0xfe, 0xfe, 0xfe, 0xfe,
	0xff, 0xff, 0xff, 0x00, 0x00, 0x00, 0x7f, 0x7f,
	0x7f, 0x3e, 0xbe, 0xff, 0xff, 0xff, 0xff, 0xff,
	0x00, 0x00, 0x00, 0x7f, 0x7f, 0x7f, 0x00, 0x00,
	0x00, 0xff, 0xff, 0xff, 0x00, 0x00, 0x00, 0xff,
	0xff, 0xff, 0xff, 0xff, 0xff, 0x00, 0x00, 0x00,
	0x7f, 0x7f, 0xff, 0xff, 0xff, 0xff, 0xff, 0xff,
	0xff, 0xff, 0xff, 0xff, 0xff, 0xff, 0xff, 0xff,
	0x7f, 0x7f, 0x7f, 0x7f, 0x7f, 0x3f, 0x3f, 0x3f,
	0x3f, 0x1f, 0x1f, 0x1f, 0x1f, 0x1f, 0x1f, 0x1f,
	0x1f, 0x1f, 0x1f, 0x1f, 0x1f, 0x1f, 0x1f, 0x1f,
	0x0f, 0x0f, 0x0f, 0x0f, 0x0f, 0x0f, 0x0f, 0x0f,
	0x0f, 0x0f, 0x07, 0x07, 0x07, 0x07, 0x07, 0x07,
	0x0f, 0x8f, 0x9f, 0x9f, 0x3f, 0x3e, 0x7e, 0xfe,
	0xfe, 0xfe, 0xfe, 0xfe, 0x3f, 0x9f, 0xdf, 0xdf,
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
};

const unsigned char final1[] PROGMEM = {
	0xff, 0xff, 0xff, 0xff, 0xff, 0xff, 0xff, 0xff,
	0xff, 0xff, 0xff, 0xff, 0xff, 0xff, 0xff, 0xff,
	0xff, 0xff, 0xff, 0xff, 0xff, 0xff, 0xff, 0xff,
	0xff, 0xff, 0xff, 0xff, 0xff, 0xff, 0xff, 0xff,
	0xff, 0xff, 0xff, 0xff, 0xff, 0xff, 0xff, 0xff,
	0xff, 0xff, 0xff, 0xff, 0xff, 0xff, 0xff, 0xff,
	0xff, 0xff, 0xff, 0xff, 0xff, 0xff, 0xff, 0xff,
	0xff, 0xff, 0xff, 0xff, 0xff, 0xff, 0xff, 0xff,
	0xff, 0xff, 0xff, 0xff, 0xff, 0xff, 0xff, 0xff,
	0xff, 0xff, 0xff, 0xff, 0xff, 0xff, 0xff, 0xff,
	0xff, 0xff, 0xff, 0xff, 0xff, 0xff, 0xff, 0xff,
	0xff, 0xcf, 0xcf, 0xcf, 0xcf, 0x8f, 0x9e, 0x9e,
	0x9c, 0x9c, 0xfc, 0xff, 0xff, 0x0f, 0x00, 0x80,
	0x50, 0xaa, 0x55, 0xaa, 0x55, 0x00, 0x00, 0xff,
	0xff, 0xff, 0xff, 0xff, 0xff, 0xff, 0xff, 0xff,
	0xff, 0xff, 0xff, 0xff, 0xff, 0xff, 0xff, 0xff,
	0xff, 0xff, 0xff, 0x7f, 0x3f, 0x3f, 0x1f, 0x9f,
	0x8f, 0xcf, 0xcf, 0xcf, 0x4f, 0x47, 0x67, 0x27,
	0x27, 0xe7, 0xa7, 0x37, 0x37, 0x37, 0x37, 0x33,
	0x73, 0xd3, 0x93, 0x93, 0x93, 0x93, 0x93, 0x93,
	0x99, 0x89, 0xc9, 0xc9, 0xc9, 0xc1, 0xc1, 0xc1,
	0xe1, 0x31, 0x18, 0x08, 0xc8, 0xc8, 0xe8, 0xf8,
	0xf1, 0xf1, 0xf3, 0xf3, 0xe7, 0xc7, 0x0f, 0x3f,
	0xff, 0xff, 0xff, 0xff, 0xff, 0xff, 0xff, 0xff,
	0xff, 0xff, 0xff, 0xff, 0xff, 0xff, 0xff, 0xff,
	0xff, 0xff, 0xff, 0xff, 0x7f, 0x7f, 0x7f, 0xff,
	0xff, 0xff, 0xff, 0xff, 0xff, 0xff, 0xff, 0xf3,
	0xf3, 0xf3, 0xf3, 0xf3, 0xf3, 0x73, 0x73, 0x73,
	0x73, 0x73, 0xff, 0xff, 0xff, 0x00, 0x00, 0xaa,
	0x55, 0xaa, 0x55, 0xaa, 0x55, 0x00, 0x00, 0xff,
	0xff, 0xff, 0xff, 0xff, 0xff, 0xff, 0xff, 0xff,
	0xff, 0xff, 0xff, 0xff, 0xff, 0xff, 0xff, 0xff,
	0xff, 0xff, 0x03, 0x00, 0x00, 0xfc, 0xff, 0xff,
	0xff, 0x03, 0x01, 0x00, 0xf0, 0xf8, 0xfc, 0xfe,
	0xfe, 0xfe, 0x07, 0x07, 0x07, 0x07, 0xc6, 0xec,
	0xe8, 0xc8, 0x0f, 0x03, 0x03, 0x03, 0x03, 0x03,
	0x03, 0x03, 0x01, 0x01, 0x01, 0x01, 0x01, 0x01,
	0x03, 0x02, 0x02, 0x19, 0x3c, 0x3c, 0x18, 0x00,
	0x00, 0xff, 0xff, 0xff, 0xff, 0xff, 0xff, 0x00,
	0xff, 0xff, 0xff, 0xff, 0xff, 0xff, 0xe7, 0xdb,
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
};

const unsigned char final2[] PROGMEM = {
	0x55, 0xab, 0x55, 0xab, 0x57, 0xab, 0x57, 0xaf,
	0x57, 0xaf, 0xdf, 0xef, 0xff, 0xff, 0xff, 0xff,
	0x00, 0x00, 0xff, 0xff, 0xff, 0xff, 0xff, 0xf8,
	0x00, 0x00, 0x00, 0x00, 0x00, 0x00, 0x00, 0x00,
	0x00, 0x00, 0x00, 0x00, 0x00, 0x00, 0x00, 0x00,
	0x00, 0x00, 0x00, 0x00, 0x00, 0x00, 0x00, 0x00,
	0x00, 0xa8, 0x54, 0xaa, 0x55, 0xaa, 0x45, 0x02,
	0x00, 0x00, 0x00, 0x00, 0x00, 0x02, 0x04, 0x80,
	0x40, 0xaa, 0x54, 0xaa, 0x55, 0xaa, 0x55, 0xaa,
	0x54, 0xaa, 0x51, 0x02, 0x00, 0x00, 0x00, 0x00,
	0x00, 0x00, 0x00, 0x00, 0x00, 0x00, 0x00, 0x00,
	0x00, 0x00, 0x00, 0x00, 0x00, 0x00, 0x00, 0x00,
	0x00, 0x00, 0x00, 0x00, 0x00, 0x00, 0x00, 0x00,
	0x00, 0xe0, 0xff, 0xff, 0xff, 0xff, 0xff, 0x00,
	0x00, 0xff, 0xff, 0xff, 0xff, 0xef, 0xdf, 0xaf,
	0x57, 0xaf, 0x57, 0xab, 0x57, 0xab, 0x55, 0xab,
	0xf5, 0xfa, 0xfd, 0xfa, 0xfd, 0xfe, 0xff, 0xff,
	0xff, 0xff, 0xff, 0xff, 0x7f, 0xff, 0xff, 0xff,
	0x00, 0x00, 0xff, 0xff, 0xff, 0xff, 0xff, 0xff,
	0xfc, 0x80, 0x00, 0x00, 0x00, 0x00, 0x00, 0x00,
	0x00, 0x00, 0x00, 0x00, 0x00, 0x00, 0x00, 0x00,
	0x00, 0x00, 0x00, 0x00, 0x00, 0x00, 0x00, 0x00,
	0x00, 0x2a, 0x55, 0xaa, 0x55, 0xaa, 0x55, 0xaa,
	0x50, 0xa0, 0x55, 0xaa, 0x44, 0x28, 0x15, 0x02,
	0x15, 0x2a, 0x15, 0x2a, 0x15, 0x2a, 0x55, 0xaa,
	0x55, 0xaa, 0x55, 0xa8, 0x50, 0xa0, 0x10, 0x00,
	0x00, 0x00, 0x00, 0x00, 0x00, 0x00, 0x00, 0x00,
	0x00, 0x00, 0x00, 0x00, 0x00, 0x00, 0x00, 0x00,
	0x00, 0x00, 0x00, 0x00, 0x00, 0x00, 0x00, 0xc0,
	0xfc, 0xff, 0xff, 0xff, 0xff, 0xff, 0xff, 0x00,
	0x00, 0xff, 0xff, 0xff, 0x7f, 0xff, 0xff, 0xff,
	0xff, 0xff, 0xff, 0xfe, 0xfd, 0xfa, 0xfd, 0xfa,
	0x55, 0xab, 0x55, 0xab, 0x55, 0xaa, 0xd5, 0xea,
	0xf5, 0xfa, 0xfd, 0xfe, 0xff, 0xff, 0x7f, 0xff,
	0x00, 0x00, 0xff, 0xff, 0xff, 0xff, 0xff, 0xff,
	0xff, 0xff, 0xf0, 0x80, 0x00, 0x00, 0x00, 0x00,
	0x00, 0x00, 0x00, 0x00, 0x00, 0x00, 0x00, 0x00,
	0x00, 0x00, 0x00, 0x00, 0x00, 0x00, 0x00, 0x00,
	0x00, 0x00, 0x00, 0x02, 0x05, 0x0a, 0x15, 0x0a,
	0x15, 0x2a, 0x55, 0x2a, 0x55, 0xa8, 0x50, 0x80,
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
	};
	
	const unsigned char final3[] PROGMEM = {
	0x80, 0x40, 0xa0, 0xf0, 0xf8, 0x3e, 0x07, 0x01,
	0x00, 0x00, 0x00, 0x00, 0x00, 0x00, 0x00, 0x00,
	0x00, 0x00, 0x00, 0x00, 0x00, 0x00, 0x00, 0x00,
	0x00, 0x00, 0x00, 0x00, 0x00, 0x00, 0x00, 0x00,
	0x00, 0x00, 0x00, 0x00, 0x00, 0x00, 0x00, 0x00,
	0x00, 0x00, 0x00, 0x00, 0x00, 0x00, 0x00, 0x00,
	0x00, 0x00, 0x00, 0x80, 0x80, 0x80, 0x80, 0x80,
	0x80, 0x00, 0x00, 0x00, 0x00, 0x00, 0x00, 0x00,
	0xfa, 0x7d, 0x0f, 0x03, 0x00, 0x00, 0x00, 0x00,
	0x00, 0x00, 0x00, 0x00, 0x00, 0x00, 0x00, 0x00,
	0x00, 0x00, 0x00, 0x00, 0x00, 0x00, 0x00, 0x00,
	0x00, 0x00, 0x00, 0x00, 0x00, 0x00, 0x00, 0x00,
	0x00, 0x00, 0x00, 0x00, 0x00, 0x00, 0x00, 0x00,
	0x00, 0x00, 0x00, 0x00, 0xc0, 0xf0, 0xb8, 0xce,
	0xe6, 0x73, 0x3b, 0x39, 0x19, 0x19, 0x39, 0xf1,
	0xe1, 0xc3, 0x03, 0x06, 0x0e, 0x3c, 0xf0, 0xc0,
	0x01, 0x00, 0x00, 0x00, 0x00, 0x00, 0x00, 0x00,
	0x00, 0x00, 0x00, 0x00, 0x00, 0x00, 0x00, 0x00,
	0x00, 0x00, 0x00, 0x00, 0x00, 0x00, 0x00, 0x00,
	0x00, 0x00, 0x00, 0x00, 0x00, 0x00, 0x00, 0x00,
	0x00, 0x00, 0x80, 0xc0, 0xc0, 0xc0, 0xc0, 0xe0,
	0xe0, 0x70, 0x38, 0x3c, 0x1f, 0x07, 0x03, 0x01,
	0x00, 0x00, 0x00, 0x00, 0x80, 0xc0, 0xe0, 0x78,
	0x3f, 0x1f, 0x00, 0x80, 0xc0, 0xf0, 0x7f, 0x1f,
	0x00, 0x00, 0x00, 0x00, 0x00, 0x00, 0x00, 0x00,
	0x00, 0x00, 0x00, 0x00, 0x00, 0x00, 0x00, 0x00,
	0x00, 0x00, 0x00, 0x00, 0x00, 0x00, 0x00, 0x00,
	0x00, 0x00, 0x00, 0x08, 0x08, 0x0c, 0x0e, 0x0e,
	0x07, 0x03, 0x01, 0x01, 0x0c, 0x0f, 0x0f, 0x07,
	0x01, 0x00, 0x00, 0x00, 0x00, 0x00, 0x00, 0x00,
	0x00, 0x0c, 0x0e, 0x07, 0x07, 0x07, 0x06, 0x06,
	0x06, 0x03, 0x03, 0x01, 0x01, 0x00, 0x00, 0x00
};

const unsigned char final4[] PROGMEM = {
	0x00, 0x00, 0x00, 0x00, 0x00, 0x20, 0x00, 0x00,
	0x00, 0x00, 0x00, 0x00, 0x00, 0x00, 0x00, 0x00,
	0x00, 0x00, 0x00, 0x00, 0x00, 0x00, 0x00, 0x00,
	0x00, 0x00, 0x00, 0x00, 0x00, 0x00, 0x08, 0x00,
	0x00, 0x00, 0x00, 0x00, 0x00, 0x00, 0x00, 0x00,
	0x00, 0x00, 0x00, 0x00, 0x00, 0x00, 0x80, 0x80,
	0xc0, 0xe0, 0xd0, 0x50, 0x00, 0x48, 0x40, 0xe0,
	0xf0, 0xf0, 0xf8, 0xfc, 0xfc, 0xfc, 0xfc, 0xfc,
	0xfc, 0xfc, 0x7c, 0x7c, 0xfc, 0xbc, 0xbc, 0xfc,
	0xf8, 0xe8, 0x08, 0x10, 0x30, 0x30, 0x20, 0x40,
	0x00, 0x80, 0x00, 0x00, 0x00, 0x00, 0x00, 0x00,
	0x00, 0x00, 0x10, 0x00, 0x00, 0x00, 0x00, 0x00,
	0x00, 0x00, 0x00, 0x00, 0x00, 0x00, 0x00, 0x00,
	0x00, 0x00, 0x00, 0x00, 0x00, 0x00, 0x02, 0x00,
	0x00, 0x00, 0x00, 0x00, 0x00, 0x00, 0x00, 0x00,
	0x00, 0x00, 0x00, 0x00, 0x00, 0x00, 0x00, 0x00,
	0x00, 0x00, 0x00, 0x00, 0x00, 0x00, 0x00, 0x00,
	0x00, 0x00, 0x00, 0x00, 0x00, 0x00, 0x00, 0x00,
	0x00, 0x00, 0x00, 0x00, 0x00, 0x00, 0x00, 0x00,
	0x00, 0x00, 0x00, 0x00, 0x00, 0x00, 0x00, 0x00,
	0x00, 0x00, 0x00, 0x00, 0x00, 0x00, 0x80, 0xc0,
	0xe0, 0xf0, 0xf8, 0xfc, 0xfe, 0xff, 0xff, 0xfb,
	0xf9, 0x18, 0x00, 0x00, 0x00, 0x00, 0x01, 0x03,
	0x03, 0x01, 0x01, 0x80, 0x81, 0x01, 0x60, 0x04,
	0x0c, 0x18, 0xf0, 0xc0, 0x80, 0x01, 0x03, 0xf7,
	0xff, 0xef, 0xe7, 0xfe, 0xfc, 0xf8, 0xf0, 0x13,
	0x3e, 0x26, 0x00, 0x00, 0x00, 0x80, 0x80, 0xa0,
	0xc0, 0x00, 0x00, 0x00, 0x00, 0x00, 0x00, 0x00,
	0x00, 0x00, 0x00, 0x00, 0x00, 0x00, 0x00, 0x00,
	0x00, 0x02, 0x00, 0x00, 0x00, 0x00, 0x00, 0x00,
	0x00, 0x00, 0x00, 0x00, 0x00, 0x00, 0x00, 0x01,
	0x00, 0x00, 0x00, 0x00, 0x00, 0x00, 0x00, 0x00,
	0x00, 0x00, 0x00, 0x00, 0x80, 0x00, 0x00, 0x00,
	0x00, 0x00, 0x00, 0x00, 0x00, 0x00, 0x00, 0x00,
	0x01, 0x00, 0x00, 0x00, 0x00, 0x00, 0x00, 0x00,
	0x00, 0x00, 0x00, 0x01, 0x00, 0x00, 0x00, 0x00,
	0x00, 0x00, 0x00, 0xe0, 0xfc, 0xff, 0xff, 0xff,
	0xff, 0xff, 0xff, 0xff, 0xff, 0x3f, 0x0f, 0x07,
	0x00, 0x00, 0x00, 0x00, 0x00, 0x00, 0x00, 0x00,
	0x00, 0x00, 0x41, 0x83, 0x07, 0x0f, 0x00, 0x00,
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
};
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
void loop() {
	if(!(arduboy.nextFrame())) {
		return;
	}
	
	frame++;
	if(frame > 260) {
		frame = 0;
	}
	if(frame % 2) {
		animation++;
		if(transitionanimation > 0) {
			transitionanimation -= 1;
			temperature = 0;
		}
	}
	
	if(animation > 7) {
		animation = 0;
	}
	
	arduboy.clear();

	switch(gamestate) {
		case 0:	//Credits Screen
			arduboy.drawBitmap(8, 8, me, 48, 48, WHITE);
			arduboy.setCursor(75, 8);
			arduboy.print(F("Jonathan"));
			arduboy.setCursor(87, 18);
			arduboy.print(F("Holmes"));
			arduboy.setCursor(86, 38);
			arduboy.print(F("@crait"));
			arduboy.setCursor(68, 49);
			arduboy.print(F("crait.net"));
			continuestate(1);
			break;
		case 1:	//Title Screen
			drawtitle();
			continuestate(2);
			break;
		case 2:	//Main Menu
			frame++;
			drawtitle();
			arduboy.fillRect(64, 0, 64, 64, BLACK);
			arduboy.fillRect(51, 1, 12, 17, WHITE);
			if(levelchecker >= 50 || levelchecker <= -5) {
				levelchecker = 0;
			}
			if(arduboy.notPressed(DOWN_BUTTON) && arduboy.notPressed(UP_BUTTON)) {
				menubuttoncounter = 0;
			}
			if(menubuttoncounter > 10) {
				menubuttonfree = true;
			}
			if(arduboy.pressed(DOWN_BUTTON)) {
				menubuttoncounter++;
				if(menubuttonfree && levelchecker != 49) {
					menubuttonfree = false;
					levelchecker += 1;
					sound(NOISEMENU, 100);
				}
			}
			if(arduboy.pressed(UP_BUTTON)) {
				menubuttoncounter++;
				if(menubuttonfree && levelchecker != -4) {
					menubuttonfree = false;
					levelchecker -= 1;
					sound(NOISEMENU, 100);
				}
			}
			if(arduboy.pressed(A_BUTTON) && menubuttonfree) {
				sound(NOISEMENUCLICK, 100);
				menubuttonfree = false;
				if(levelchecker == -4) {
					gamestate = 4;
					maxlevel = 0;
					EEPROM.put(SAVELOCATION, maxlevel);
				} else if(levelchecker == -3) {
					soundon = !soundon;
				} else if(levelchecker == -2) {
					gamestate = 0;
				} else if(levelchecker == -1) {
					gamestate = 3;
				} else {
					if(levelchecker <= maxlevel) {
						gamestate = 5;
						loadlevel(levelchecker);
					}
				}
			}
			printmenuitem(levelchecker - 2, 2);
			printmenuitem(levelchecker - 1, 10);
			arduboy.drawLine(64, 19, 128, 19, WHITE);
			arduboy.drawLine(64, 20, 128, 20, WHITE);
			arduboy.drawLine(64, 31, 128, 31, WHITE);
			arduboy.drawLine(64, 32, 128, 32, WHITE);
			printmenuitem(levelchecker, 22);
			printmenuitem(levelchecker + 1, 34);
			printmenuitem(levelchecker + 2, 42);
			printmenuitem(levelchecker + 3, 50);
			printmenuitem(levelchecker + 4, 58);
			break;
		case 3:	//Instruction Screen
			arduboy.setCursor(0, 0);
			arduboy.print(F("     Instructions"));
			arduboy.setCursor(0, 18);
			arduboy.print(F("    Find all sockets"));
			arduboy.setCursor(0, 28);
			arduboy.print(F("    Insert components"));
			arduboy.setCursor(0, 38);
			arduboy.print(F("    Proceed to exit"));
			arduboy.drawBitmap(6, 18, spritesheet[CHIPO], 8, 8, WHITE);
			arduboy.drawBitmap(6, 28, spritesheet[CHIPI], 8, 8, WHITE);
			arduboy.drawBitmap(6, 38, spritesheet[38 + animation % 4], 8, 8, WHITE);
			continuestate(31);
			break;
		case 31: //Controls
			arduboy.setCursor(0, 0);
			arduboy.print(F("       Controls"));
			arduboy.setCursor(0, 18);
			arduboy.print(F(" D-Pad: Move Around"));
			arduboy.setCursor(0, 28);
			arduboy.print(F("Hold A: Restart Level"));
			continuestate(2);
			break;
    case 4:	//Erased
			arduboy.setCursor(0, 0);
			arduboy.print(F("       Complete\n\n"));
			arduboy.print(F("All saved data was\n"));
			arduboy.print(F("erased..."));
			continuestate(2);
			break;
    case 5:	//Game
			arduboy.drawBitmap(112, 0, side, 16, 64, WHITE);
			arduboy.drawBitmap(112, 56, signals[animation / 2], 16, 8,  WHITE);
			if(level >= 9) {
				arduboy.setCursor(114, 29);
			} else {
				arduboy.setCursor(117, 29);
			}
			arduboy.print((int)(level + 1));
			drawlevel();
			if(transitionanimation == 0 && gamebuttonfree) {
				char index = playerx / 8 + playery / 8 * 14;
				if(gamebuttonfree && arduboy.pressed(UP_BUTTON) && checkcollision(playerx / 8, (playery - 8) / 8) && currentmap[index] != HTROT && currentmap[index] != TLROT && currentmap[index] != TRROT) {
					rotateinplace(index);
					playertoy -= 8;
					transitionanimation = 9;
					canswitch = true;
					gamebuttonfree = false;
				}
				if(gamebuttonfree && arduboy.pressed(DOWN_BUTTON) && checkcollision(playerx / 8, (playery + 8) / 8) && currentmap[index] != HTROT && currentmap[index] != BLROT && currentmap[index] != BRROT) {
					rotateinplace(index);
					playertoy += 8;
					transitionanimation = 9;
					canswitch = true;
					gamebuttonfree = false;
				}
				if(gamebuttonfree && arduboy.pressed(LEFT_BUTTON) && checkcollision((playerx - 8) / 8, playery / 8) && currentmap[index] != VTROT && currentmap[index] != TLROT && currentmap[index] != BLROT) {
					rotateinplace(index);
					playertox -= 8;
					transitionanimation = 9;
					canswitch = true;
					gamebuttonfree = false;
				}
				if(gamebuttonfree && arduboy.pressed(RIGHT_BUTTON) && checkcollision((playerx + 8) / 8, playery / 8) && currentmap[index] != VTROT && currentmap[index] != TRROT && currentmap[index] != BRROT) {
					rotateinplace(index);
					playertox += 8;
					transitionanimation = 9;
					canswitch = true;
					gamebuttonfree = false;
				}
			} else {
				menubuttonfree = false;
			}
			
			if(playery > playertoy) {
				playery -= 1;
			}
			if(playery < playertoy) {
				playery += 1;
			}
			if(playerx > playertox) {
				playerx -= 1;
			}
			if(playerx < playertox) {
				playerx += 1;
			}
			if(playery == playertoy && playerx == playertox) {
				checklocation(playerx / 8, playery / 8);
				gamebuttonfree = true;
			} else {
				arduboy.drawPixel(playertox, playertoy, WHITE);
				arduboy.drawPixel(playertox + 7, playertoy, WHITE);
				arduboy.drawPixel(playertox, playertoy + 7, WHITE);
				arduboy.drawPixel(playertox + 7, playertoy + 7, WHITE);
			}
			if(arduboy.pressed(A_BUTTON) && menubuttonfree && gamebuttonfree) {
				temperature += 1;
				sound(100 + temperature * 10, 100);
			}
			
			if(temperature > 0) {
				arduboy.fillRect(112, 0, 16, 40, BLACK);
				arduboy.drawBitmap(112, 0, temptop, 16, 8, WHITE);
				arduboy.drawBitmap(112, 8, tempmiddle, 16, 8, WHITE);
				arduboy.drawBitmap(112, 16, tempmiddle, 16, 8, WHITE);
				arduboy.drawBitmap(112, 24, tempbottom, 16, 16, WHITE);
				arduboy.fillRect(119, 37 - temperature, 2, temperature, WHITE);
			}
			if(temperature == 32) {
				deathcounter = 1;
				temperature = 33;
			}
			
			checkcompletion();
			
			if(deathcounter == 0) {
				arduboy.drawBitmap(playerx, playery, character[0], 8, 8, WHITE);
				arduboy.drawBitmap(playerx, playery, character[1], 8, 8, BLACK);
			} else {
				digitalWrite(RED_LED, ON);
				digitalWrite(GREEN_LED, OFF);
				if((deathcounter - 1) / 8 == 0) {
					sound(NOISEEXPLOSION1, 150);
				}
				if((deathcounter - 1) / 8 == 1) {
					sound(NOISEEXPLOSION2, 150);
				}
				if((deathcounter - 1) / 8 == 2) {
					sound(NOISEEXPLOSION3, 150);
				}
				if((deathcounter - 1) / 8 == 3) {
					sound(NOISEEXPLOSION4, 150);
				}
				gamebuttonfree = false;
				temperature = 33;
				deathcounter += 1;
				arduboy.drawBitmap(playerx, playery, character[1], 8, 8, BLACK);
				arduboy.drawBitmap(playerx - 2, playery - 2, deathsheet[(deathcounter - 1) / 8], 12, 12, WHITE);
				if(deathcounter == 32) {
					loadlevel(level);
					menubuttonfree = false;
				}
			}
			break;




		case 6:
			arduboy.setCursor(0, 0);
			arduboy.print(F("\nAnd now...\n\nYou will finally see\nwhat Circuit Dude has\nbeen building these\ncomputer chips for..."));
			continuestate(7);
			break;
		case 7:
			arduboy.drawBitmap(0, 0, final1, 128, 64, WHITE);
			continuestate(8);
			break;
		case 8:
			arduboy.drawBitmap(0, 0, final2, 128, 64, WHITE);
			continuestate(9);
			break;
		case 9:
			arduboy.drawBitmap(0, 0, final2, 128, 64, WHITE);
			arduboy.fillRect(10, 36, 64, 28, WHITE);
			arduboy.drawBitmap(10, 36, final3, 64, 28, BLACK);
			continuestate(10);
			break;
		case 10:
			arduboy.drawBitmap(0, 0, final4, 128, 64, WHITE);
			continuestate(11);
			break;
		case 11:
			arduboy.drawBitmap(0, 0, final5, 128, 64, WHITE);
			continuestate(12);
			break;
		case 12:
			arduboy.setCursor(0, 0);
			arduboy.print(F("The End..."));
			continuestate(0);
			break;
  }

	if(arduboy.notPressed(A_BUTTON) && gamestate != 2) {
		menubuttonfree = true;
		temperature = 0;
	}
	if(arduboy.notPressed(DOWN_BUTTON) && arduboy.notPressed(UP_BUTTON) && arduboy.notPressed(A_BUTTON) && gamestate == 2) {
		menubuttonfree = true;
	}
	
	arduboy.display();
}

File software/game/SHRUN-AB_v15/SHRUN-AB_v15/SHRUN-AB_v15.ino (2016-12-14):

/*
 SHADOW RUNNER: http://www.team-arg.org/shrun-manual.html
 
 Arduboy version 1.5 : http://www.team-arg.org/more-about.html
 
 MADE by TEAM a.r.g. : http://www.team-arg.org/more-about.html

 2015 - JO3RI - Trodoss

 Special thanks to Dreamer3 for helping with the conversion

 SimpleButtons: Dreamer3 https://github.com/yyyc514/ArduboyExtra
 ArduboyLib: Dreamer3 https://github.com/yyyc514/ArduboyLib

 Game License: MIT : https://opensource.org/licenses/MIT

 */

//determine the game
#define GAME_ID 15

#include <SPI.h>
#include <EEPROM.h>
#include "Arglib.h"
#include "otherbitmaps.h"
#include "candlebitmaps.h"
#include "numberbitmaps.h"
#include "runnerbitmaps.h"
#include "backgroundbitmaps.h"
#include "fencebitmap.h"
#include "forgroundbitmaps.h"
#include "itembitmaps.h"

//define menu states (on main menu)
#define STATE_MENU_MAIN          0
#define STATE_MENU_HELP          1
#define STATE_MENU_CREDITS       2
#define STATE_MENU_SOUND         3

//define menu choices (on main menu)
#define CHOOSE_HELP              0
#define CHOOSE_INFO              1
#define CHOOSE_SOUND             2
#define CHOOSE_PLAY              3

#define GAME_INIT    4
#define GAME_PLAYING 5
#define GAME_PAUSED  6
#define GAME_OVER    7

#define RUNNER_RUNNING 0
#define RUNNER_JUMPING 8
#define RUNNER_DUCKING 9

Arduboy arduboy;
SimpleButtons buttons (arduboy);

//determines the state of the game
unsigned char gameState = STATE_MENU_MAIN;

// These are all getting a value in STATE_GAME_INIT
int life;
unsigned long score;
unsigned long previousScore;
byte level;

//generic variable to store menuSelection (on screens)
unsigned char menuSelection;
boolean soundYesNo = false;

//these are used for the runner animation in the mainscreen
int runnerX = -127;
int runnerY = 0;
boolean show_runner = false;
byte runnerframe = 0;
bool jumping = false;
bool ducking = false;
byte leap[] = {19, 13, 8, 6, 8, 13, 19};

byte showitems =  B00000000;        // this byte holds all the items the player runs into during the game
//                   | ||||
//                   | |||└->  stone1
//                   | ||└-->  stone2
//                   | |└--->  bird1
//                   | └---->  bird2
//                   |
//                   └------>  extra life


byte birdframe = 0;
byte flameid = 0;
boolean heartframe = 0;
int background1step = 0;
int background2step = 128;
byte background1id = 0;
byte background2id = 1;
int fence1step = 0;
int fence2step = 128;
byte fence1id = 0;
byte fence2id = 1;
int forgroundstep = 128;
byte forgroundid = 0;


int itemX[6] = { -64, 96, 48, 128, 128};

void setup () {
  arduboy.start();
  arduboy.setFrameRate(60);
  arduboy.drawBitmap(0, 8, TEAMarg2, 128, 48, 1);
  arduboy.display();
  delay(3000);
  arduboy.clearDisplay();
  gameState = STATE_MENU_MAIN;
  if (EEPROM.read(EEPROM_AUDIO_ON_OFF)) soundYesNo = true;
  menuSelection = CHOOSE_PLAY;
}

void loop() {
  if (!(arduboy.nextFrame())) return;
  buttons.poll();
  if (soundYesNo == true) arduboy.audio.on();
  else arduboy.audio.off();
  switch (gameState)
  {
    case STATE_MENU_MAIN:
      if (arduboy.everyXFrames(4))
      {
        // show the splash art
        arduboy.fillRect(0, 0, 128, 30, 0);
        arduboy.drawBitmap(16, 0, shadowRunner_bitmap, 94, 24, 1);
        arduboy.drawBitmap(49, 26, menu_bitmap, 32, 32, 1);
        arduboy.fillRect(89, 42, 16, 8, 0);
        switch (soundYesNo) {
          case true:
            arduboy.drawBitmap(89, 42, yes_bitmap, 16, 8, 1);
            break;
          case false:
            arduboy.drawBitmap(89, 42, no_bitmap, 14, 8, 1);
            break;
        }
        arduboy.fillRect(8, 18, 38, 46, 0);
        candle_draw(29, menuSelection * 8);
        for (byte i = 0; i < 4; i++)
        {
          if (menuSelection != i) {
            arduboy.drawBitmap(49, (i * 8) + 26, shade_bitmap, 32, 8, 0);
            arduboy.drawBitmap(82, (i * 8) + 26, shade_bitmap, 32, 8, 0);
          }
        }

        if (show_runner)
        {
          arduboy.drawBitmap(runnerX,-2,spotlight_bitmap,32,32,1);
          runner_draw();
        }
        runnerY = 0;
        runnerX += 4;
        if (runnerX > 127)
        {
          runnerX = -127;
          show_runner = !show_runner;
        }
        arduboy.display();
      }
      if (buttons.justPressed(UP_BUTTON) && (menuSelection > 0)) menuSelection--;
      if (buttons.justPressed(DOWN_BUTTON) && (menuSelection < 3)) menuSelection++;
      if (buttons.justPressed(A_BUTTON | B_BUTTON | LEFT_BUTTON | RIGHT_BUTTON))
      {
        switch (menuSelection)
        {
          case 0:
            arduboy.clearDisplay();
            arduboy.drawBitmap(31, 0, qrcode_bitmap, 64, 64, 1);
            arduboy.display();
            gameState = STATE_MENU_HELP;
            break;
          case 1:
            arduboy.clearDisplay();
            arduboy.fillRect(0, 0, 128, 64, 0);
            arduboy.drawBitmap(16, 0, shadowRunner_bitmap, 94, 24, 1);
            arduboy.drawBitmap(15, 23, info_bitmap, 96, 40, 1);
            arduboy.display();
            gameState = STATE_MENU_CREDITS;
            break;
          case 2:
            soundYesNo = !soundYesNo;
            if (soundYesNo == true) arduboy.audio.on();
            else arduboy.audio.off();
            arduboy.audio.save_on_off();
            break;
          case 3:
            arduboy.clearDisplay();
            arduboy.display();
            gameState = GAME_INIT;
            break;
        }
      }
      break;
    case STATE_MENU_HELP:
    case STATE_MENU_CREDITS:
      {
        if (buttons.justPressed(A_BUTTON | B_BUTTON | LEFT_BUTTON | RIGHT_BUTTON))
        {
          arduboy.clearDisplay();
          arduboy.display();
          gameState = STATE_MENU_MAIN;
        }
      }
      break;

    //******* Game-specific events **************
    case GAME_OVER:
      arduboy.fillRect(0, 0, 128, 64, 0);
      arduboy.drawBitmap(31, 16, gameover_bitmap, 64, 24, 1);
      score_draw(28, 40);
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

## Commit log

2016-11-07 initial directories
    [faboy.sch]
2016-11-07 add BOM, datasheet and Arduboy proto files
    [Arduboy BOM R2.xls, BOM.xlsx, Business Card5x.brd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]
2016-11-11 schematics oled and cpu
    [faboy.sch]
2016-11-11 schematics leds on switch / pcb border
    [BOM.xlsx, faboy.brd, faboy.sch]
2016-11-15 schematics > dcdc, switch and battery / pcb > round courner
    [BOM.xlsx, faboy.brd, faboy.sch]
2016-11-17 schematics > rgb led / pcb > via size route
    [BOM.xlsx, faboy.brd, faboy.sch]
2016-11-17 pcb > start to re-arange the pin
    [faboy.brd, faboy.sch]
2016-11-18 pcb > route oled, a and b pushbutton / change via size to 0.4mm / add QR code on layer 200 and 2001
    [faboy.brd, faboy.sch]
2016-11-20 schematics > power path / pcb > only for 0.96 display
    [BOM.xlsx, faboy.brd, faboy.sch]
2016-11-20 pcb > end of routing
    [BOM.xlsx, faboy.brd, faboy.sch]
2016-11-20 pcb > final with silk
    [faboy.brd, faboy.sch]
2016-11-23 first order
    [BOM.xlsx]
2016-11-23 change the usb connector to micro B
    [faboy.brd, faboy.sch]
2016-11-29 soft > add faboy in core lib
    [faboy.brd, faboy.sch]
2016-12-14 add games
    [BOM.xlsx, faboy.brd, faboy.sch]
2016-12-21 remove QR code and vcc plane fix
    [faboy.brd]
2017-02-08 start the BLE version
    [faboy_ble.brd, faboy_ble.sch]
2017-02-17 pcb ble routing
    [faboy_ble.brd, faboy_ble.sch]
2017-02-22 ble pcb design done
    [faboy_ble.brd, faboy_ble.sch, faboy_ble_tuned.brd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]

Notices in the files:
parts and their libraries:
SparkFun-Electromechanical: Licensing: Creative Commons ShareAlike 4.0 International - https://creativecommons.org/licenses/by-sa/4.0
